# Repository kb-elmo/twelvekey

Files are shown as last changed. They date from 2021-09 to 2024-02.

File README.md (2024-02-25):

# Twelvekey

[][cc-by-nc-sa]<a href="https://ko-fi.com/kb_elmo">kofibadge</a>

### Simple 12-key mechanical macropad

front_view

---

[STEP files for the case](case/)

[KiCAD PCB files](pcb/)

[Gerbers for PCB production](pcb/fab/twelvekey.zip)

[JLCPCB BOM](pcb/fab/twelvekey_bom_jlc.csv)

[JLCPCB CPL](pcb/fab/twelvekey_cpl_jlc.csv)

[Vial-QMK firmware](firmware/vial-qmk)

---

back_view

---

This work is licensed under a
[Creative Commons Attribution-NonCommercial-ShareAlike 4.0 International License][cc-by-nc-sa].

[][cc-by-nc-sa]

[cc-by-nc-sa]: http://creativecommons.org/licenses/by-nc-sa/4.0/
[cc-by-nc-sa-image]: https://licensebuttons.net/l/by-nc-sa/4.0/88x31.png
[cc-by-nc-sa-shield]: https://img.shields.io/badge/License-CC%20BY--NC--SA%204.0-lightgrey.svg

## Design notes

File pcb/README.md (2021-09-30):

# Twelvekey PCB

### Features

- In-switch LEDs
- Powered by an Atmega328p
- Basic ESD and overvoltage protection
- Centered USB type-C port for a detachable cable
- Fully programmable using [QMK](https://qmk.fm) and [Vial](https://get.vial.today)

---

### Preview

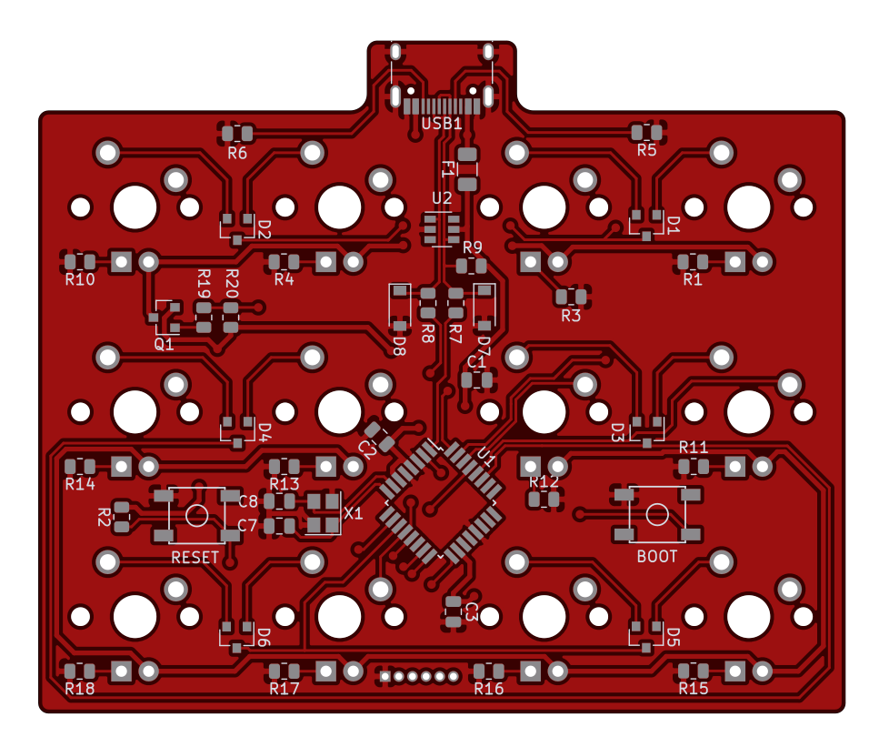
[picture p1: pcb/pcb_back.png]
pcb_back
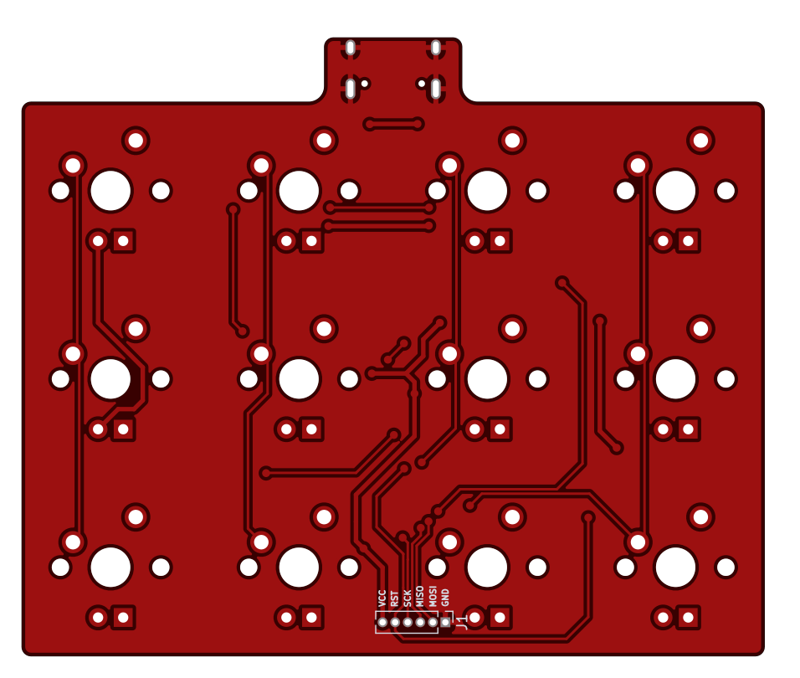
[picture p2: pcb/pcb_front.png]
pcb_front


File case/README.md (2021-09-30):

# Twelvekey case

### These files are meant for 3D printing only! 

They are not suitable for CNC machining and trying to use them for that will most likely result in failure of the parts.

The top piece should be printed upside down with supports for the integrated plate to get the best looking results.  
The bottom can be printed without any supports in it's natural orientation.

The bottom part is a simple friction fit into the top.  
Make sure that everything works and is installed properly on the PCB when putting the case together.  
Removing the bottom piece later is not really easy.

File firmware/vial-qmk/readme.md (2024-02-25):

# Twelvekey

twelvekey

Simple 12-key macropad

* Keyboard Maintainer: [kb-elmo](https://github.com/kb-elmo)
* Hardware Supported: Twelvekey PCB with backlight
* Hardware Availability: [Open source project](https://github.com/kb-elmo/twelvekey)

Make example for this keyboard (after setting up your build environment):

    make kb_elmo/twelvekey:default

Flashing example for this keyboard:

    make kb_elmo/twelvekey:default:flash

See the [build environment setup](https://docs.qmk.fm/#/getting_started_build_tools) and the [make instructions](https://docs.qmk.fm/#/getting_started_make_guide) for more information. Brand new to QMK? Start with our [Complete Newbs Guide](https://docs.qmk.fm/#/newbs).

## Bootloader

* **Bootmagic reset**: Hold down the top left key and plug in the keyboard
* **Physical reset button**: Hold down the button labeled "BOOT" and briefly press the button labeled "RESET" on the back of the PCB

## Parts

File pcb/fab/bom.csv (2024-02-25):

Designator | Footprint | Quantity | Value | LCSC Part #
BOOT, RESET | SKQG-1155865 | 2 | SW_Push | C2762971
C1 | 0805 | 1 | 10uF | C1713
C2, C3 | 0805 | 2 | 0.1uF | C38141
C7, C8 | 0805 | 2 | 22pF | C24658
D1, D2, D3, D4, D5, D6 | D_SOT-23_ANK | 6 | D_Small | C408391
D7, D8 | D_SOD-123 | 2 | D_Zener_Small | C173412
F1 | 1206 | 1 | Polyfuse_Small | C151133
J1 | PinHeader_1x06_P1.27mm_Vertical | 1 | Conn_01x06
MX1, MX10, MX11, MX12, MX2, MX3, MX4, MX5, MX6, MX7, MX8, MX9 | MXOnly-1U | 12 | MX-LED
Q1 | SOT-23 | 1 | AO3401A | C15127
R1, R10, R11, R12, R13, R14, R15, R16, R17, R18, R3, R4 | 0805 | 12 | 1k | C17513
R19 | 0805 | 1 | 100R | C17408
R2, R20 | 0805 | 2 | 10k | C17414
R5, R6 | 0805 | 2 | 5.1k | C27834
R7, R8 | 0805 | 2 | 68R | C17802
R9 | 0805 | 1 | 1.5K | C4310
U1 | TQFP-32_7x7mm_P0.8mm | 1 | ATmega328P-A | C14877
U2 | SOT-23-6 | 1 | SRV05-4 | C558418
USB1 | USB_C_Receptacle_HRO_TYPE-C-31-M-12 | 1 | USB_C_Receptacle_USB2.0 | C165948
X1 | Crystal_SMD_3225-4Pin_3.2x2.5mm | 1 | Crystal_GND24_Small | C13738

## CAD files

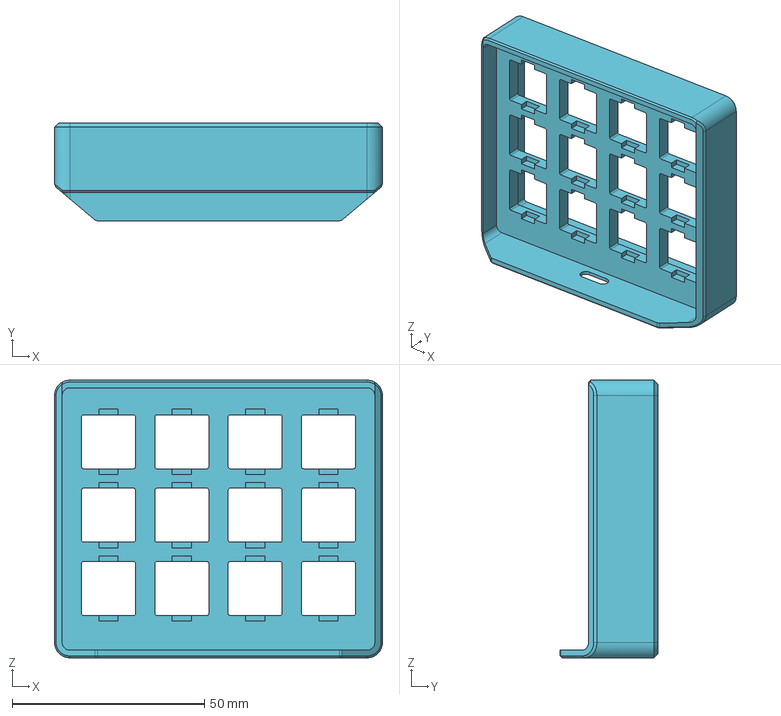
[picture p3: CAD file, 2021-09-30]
case/top.step
85.2 x 25.4 x 72.2 mm

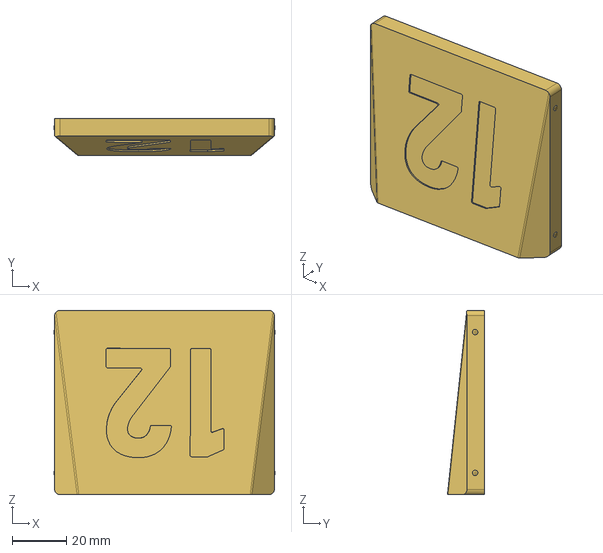
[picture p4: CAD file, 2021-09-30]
case/bottom.step
81.2 x 13.7 x 67.8 mm

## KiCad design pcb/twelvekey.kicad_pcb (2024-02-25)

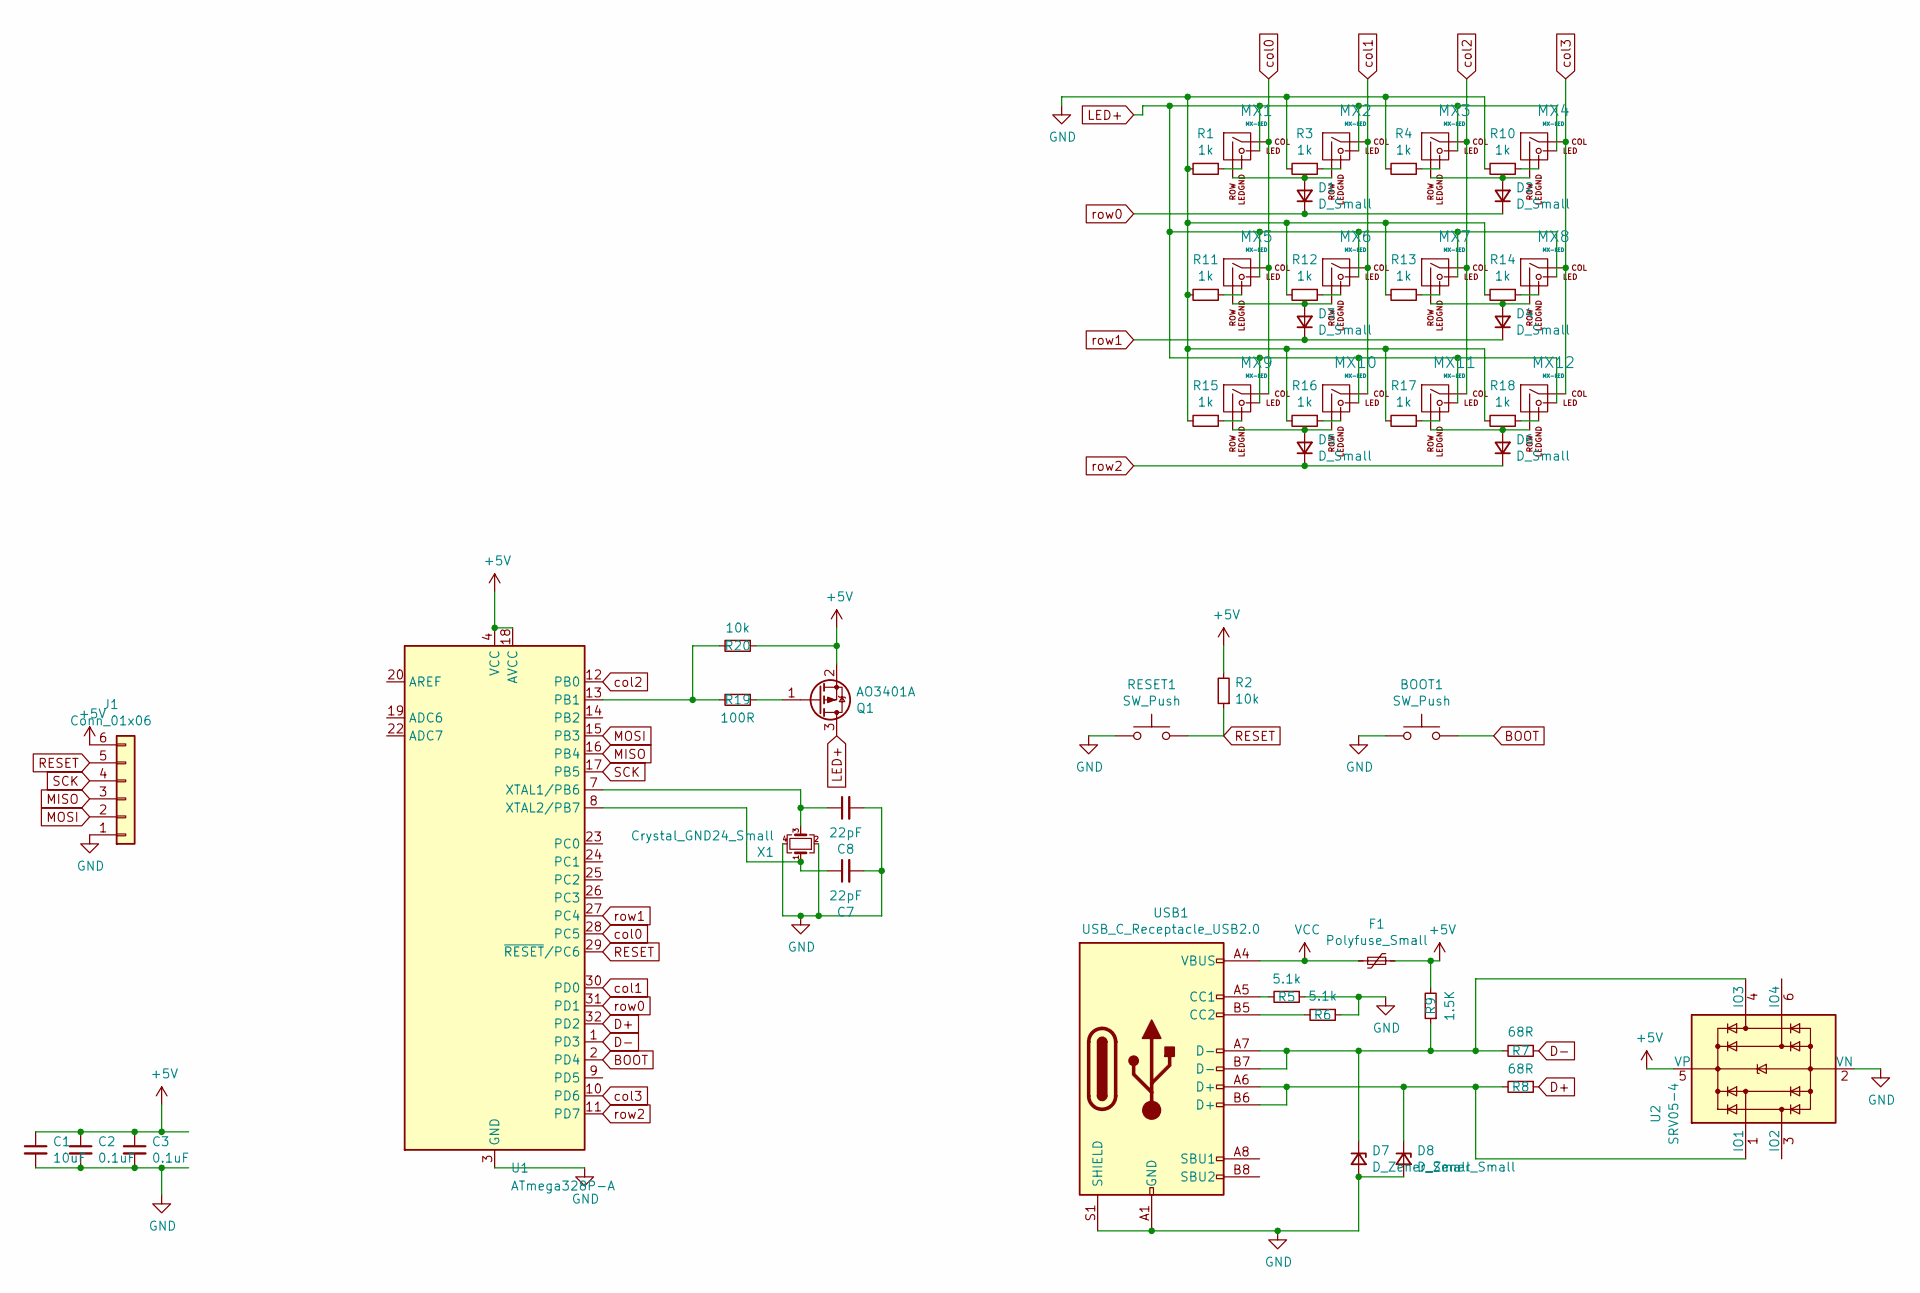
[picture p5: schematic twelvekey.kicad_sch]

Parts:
BOOT1: SW_Push; SKQG-1155865; LCSC C2762971
C1: 10uF; C_0805_2012Metric; LCSC C1713
C2, C3: 0.1uF; C_0805_2012Metric; LCSC C38141
C7, C8: 22pF; C_0805_2012Metric; LCSC C24658
D1, D2, D3, D4, D5, D6: D_Small; D_SOT-23_ANK; LCSC C408391
D7, D8: D_Zener_Small; D_SOD-123; LCSC C173412
F1: Polyfuse_Small; Fuse_1206_3216Metric; LCSC C151133
J1: Conn_01x06; PinHeader_1x06_P1.27mm_Vertical
MX1, MX2, MX3, MX4, MX5, MX6, MX7, MX8, MX9, MX10, MX11, MX12: MX-LED; MXOnly-1U
Q1: AO3401A; SOT-23; LCSC C15127
R1, R3, R4, R10, R11, R12, R13, R14, R15, R16, R17, R18: 1k; R_0805_2012Metric; LCSC C17513
R2, R20: 10k; R_0805_2012Metric; LCSC C17414
R5, R6: 5.1k; R_0805_2012Metric; LCSC C27834
R7, R8: 68R; R_0805_2012Metric; LCSC C17802
R9: 1.5K; R_0805_2012Metric; LCSC C4310
R19: 100R; R_0805_2012Metric; LCSC C17408
RESET1: SW_Push; SKQG-1155865; LCSC C2762971
U1: ATmega328P-A; TQFP-32_7x7mm_P0.8mm; LCSC C14877
U2: SRV05-4; SOT-23-6; LCSC C558418
USB1: USB_C_Receptacle_USB2.0; USB_C_Receptacle_HRO_TYPE-C-31-M-12; LCSC C165948
X1: Crystal_GND24_Small; Crystal_SMD_3225-4Pin_3.2x2.5mm; LCSC C13738

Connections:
+5V: C1.1, C2.1, C3.1, F1.1, J1.6, Q1.2 (S), R2.2, R9.2, R20.1, U1.4 (VCC), U1.6 (VCC), U1.18 (AVCC), U2.5 (VP)
BOOT: BOOT1.2, U1.2 (PD4); also elsewhere on the board
D+: R8.1, U1.32 (PD2)
D-: R7.1, U1.1 (PD3)
GND: BOOT1.1, C1.2, C2.2, C3.2, C7.2, C8.2, D7.2 (A), D8.2 (A), J1.1, R1.2, R3.2, R4.2, R5.1, R6.1, R10.2, R11.2, R12.2, R13.2, R14.2, R15.2, R16.2, R17.2, R18.2, RESET1.1, U1.3 (GND), U1.5 (GND), U1.21 (GND), U2.2 (VN), USB1.A1 (GND), USB1.A12 (GND), USB1.B1 (GND), USB1.B12 (GND), USB1.S1 (SHIELD), X1.2, X1.4; also elsewhere on the board
LED+: MX1.3 (LED), MX2.3 (LED), MX3.3 (LED), MX4.3 (LED), MX5.3 (LED), MX6.3 (LED), MX7.3 (LED), MX8.3 (LED), MX9.3 (LED), MX10.3 (LED), MX11.3 (LED), MX12.3 (LED), Q1.3 (D)
MISO: J1.3, U1.16 (PB4)
MOSI: J1.2, U1.15 (PB3)
unnamed: D1.2 (A), MX1.2 (ROW), MX2.2 (ROW)
unnamed: D2.2 (A), MX3.2 (ROW), MX4.2 (ROW)
unnamed: D3.2 (A), MX5.2 (ROW), MX6.2 (ROW)
unnamed: D4.2 (A), MX7.2 (ROW), MX8.2 (ROW)
unnamed: D5.2 (A), MX9.2 (ROW), MX10.2 (ROW)
unnamed: D6.2 (A), MX11.2 (ROW), MX12.2 (ROW)
unnamed: D7.1 (K), R7.2, R9.1, U2.4 (IO3), USB1.A7 (D-), USB1.B7 (D-)
unnamed: D8.1 (K), R8.2, U2.1 (IO1), USB1.A6 (D+), USB1.B6 (D+)
unnamed: MX1.4 (LEDGND), R1.1
unnamed: MX2.4 (LEDGND), R3.1
unnamed: MX3.4 (LEDGND), R4.1
unnamed: MX4.4 (LEDGND), R10.1
unnamed: MX5.4 (LEDGND), R11.1
unnamed: MX6.4 (LEDGND), R12.1
unnamed: MX7.4 (LEDGND), R13.1
unnamed: MX8.4 (LEDGND), R14.1
unnamed: MX9.4 (LEDGND), R15.1
unnamed: MX10.4 (LEDGND), R16.1
unnamed: MX11.4 (LEDGND), R17.1
unnamed: MX12.4 (LEDGND), R18.1
unnamed: Q1.1 (G), R19.1
unnamed: R19.2, R20.2, U1.13 (PB1)
unnamed: C8.1, U1.7 (XTAL1/PB6), X1.3
unnamed: C7.1, U1.8 (XTAL2/PB7), X1.1
unnamed: R5.2, USB1.A5 (CC1)
unnamed: R6.2, USB1.B5 (CC2)
RESET: J1.5, R2.1, RESET1.2, U1.29 (~RESET/PC6); also elsewhere on the board
SCK: J1.4, U1.17 (PB5)
VCC: F1.2, USB1.A4 (VBUS), USB1.A9 (VBUS), USB1.B4 (VBUS), USB1.B9 (VBUS)
col0: MX1.1 (COL), MX5.1 (COL), MX9.1 (COL), U1.28 (PC5)
col1: MX2.1 (COL), MX6.1 (COL), MX10.1 (COL), U1.30 (PD0)
col2: MX3.1 (COL), MX7.1 (COL), MX11.1 (COL), U1.12 (PB0)
col3: MX4.1 (COL), MX8.1 (COL), MX12.1 (COL), U1.10 (PD6)
row0: D1.1 (K), D2.1 (K), U1.31 (PD1)
row1: D3.1 (K), D4.1 (K), U1.27 (PC4)
row2: D5.1 (K), D6.1 (K), U1.11 (PD7)

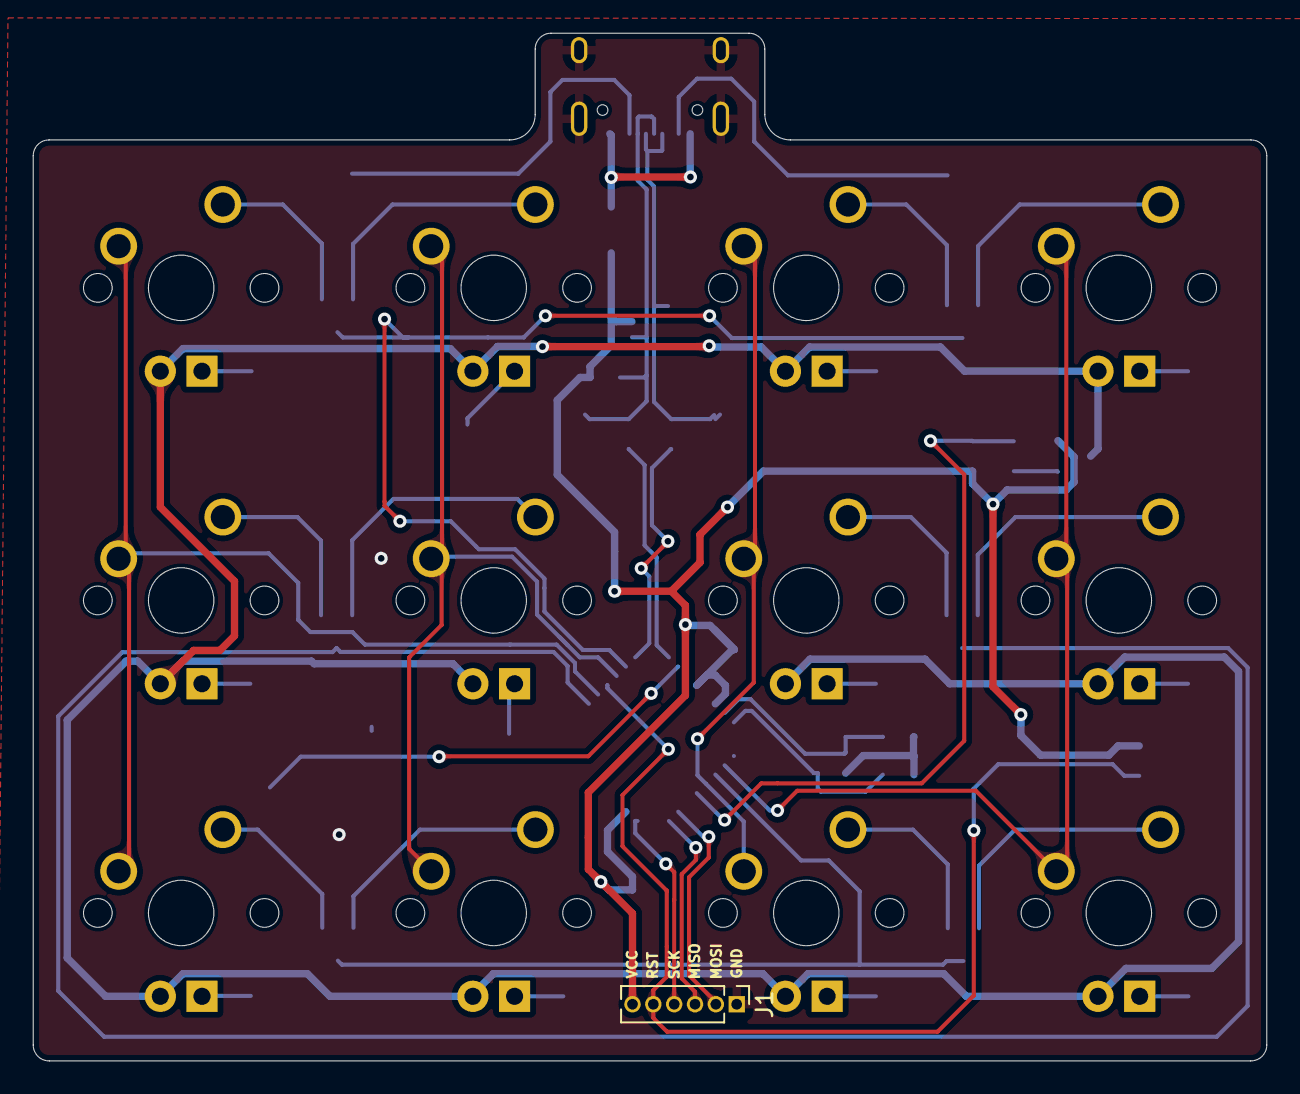
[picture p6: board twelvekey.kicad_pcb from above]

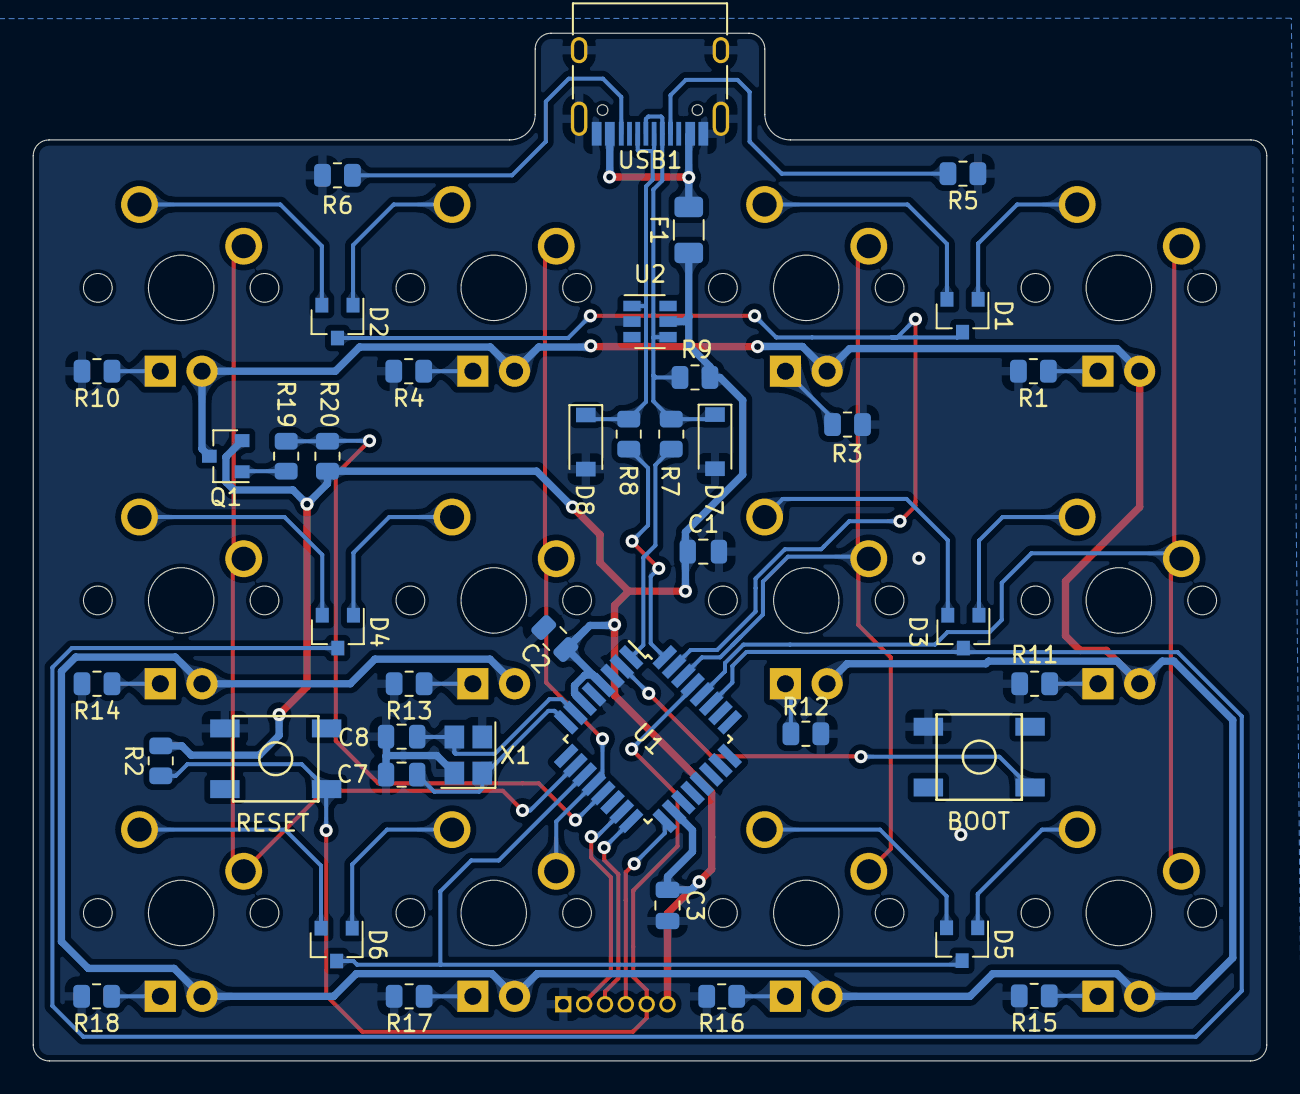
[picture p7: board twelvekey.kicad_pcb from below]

Board: 2 copper layers, 75.2 x 62.6 mm, 54 parts (41 on the bottom side), 44 nets.

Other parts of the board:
BOOT: SW_Push; SKQG-1155865
RESET: SW_Push; SKQG-1155865

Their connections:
BOOT: BOOT.2; also elsewhere on the board
GND: BOOT.1, RESET.1; also elsewhere on the board
RESET: RESET.2; also elsewhere on the board

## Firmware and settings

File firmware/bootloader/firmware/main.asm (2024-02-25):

main.elf:     file format elf32-avr

SYMBOL TABLE:
00800100 l    d  .data	00000000 .data
00007000 l    d  .text	00000000 .text
00800106 l    d  .bss	00000000 .bss
0080013b l    d  .noinit	00000000 .noinit
00000000 l    d  .stab	00000000 .stab
00000000 l    d  .stabstr	00000000 .stabstr
00000000 l    d  .comment	00000000 .comment
00000000 l    d  .note.gnu.avr.deviceinfo	00000000 .note.gnu.avr.deviceinfo
00000000 l    d  .debug_info	00000000 .debug_info
00000000 l    d  .debug_abbrev	00000000 .debug_abbrev
00000000 l    d  .debug_line	00000000 .debug_line
00000000 l    d  .debug_str	00000000 .debug_str
00000000 l    df *ABS*	00000000 main.c
0000003e l       *ABS*	00000000 __SP_H__
0000003d l       *ABS*	00000000 __SP_L__
0000003f l       *ABS*	00000000 __SREG__
00000000 l       *ABS*	00000000 __tmp_reg__
00000001 l       *ABS*	00000000 __zero_reg__
000070f4 l       .text	00000000 __BOOTLOADERENTRY_FROMSOFTWARE__bootup_investigate_RAMEND_done5
000070f2 l       .text	00000000 __BOOTLOADERENTRY_FROMSOFTWARE__bootup_investigate_RAMEND_mismatch5
0080013c l     O .noinit	00000001 __BOOTLOADERENTRY_FROMSOFTWARE__bootup_RAMEND_doesmatch
0080013b l     O .noinit	00000001 __BOOTLOADERENTRY_FROMSOFTWARE__bootup_MCUCSR
00800102 l     O .data	00000004 signatureBytes
0080010f l     O .bss	00000001 stayinloader
00007430 l       .text	00000000 _mywait_sleeploop156
00007496 l       .text	00000000 _mywait_sleeploop231
00800110 l     O .bss	00000001 usbMsgFlags
00800106 l     O .bss	00000004 replyBuffer.2269
0080010d l     O .bss	00000002 currentAddress
0080010c l     O .bss	00000001 bytesRemaining
0080010b l     O .bss	00000001 isLastPage
0080010a l     O .bss	00000001 currentRequest
00800100 l     O .data	00000001 usbMsgLen
00000000 l    df *ABS*	00000000 _clear_bss.o
0000711c l       .text	00000000 .do_clear_bss_start
0000711a l       .text	00000000 .do_clear_bss_loop
00000000 l    df *ABS*	00000000 usbdrv/usbdrvasm.o
0000714c l       .text	00000000 usbCrcLoopEntry
0000713a l       .text	00000000 usbCrcByteLoop
0000713e l       .text	00000000 usbCrcBitLoop
00007148 l       .text	00000000 usbCrcNoXor
00007150 l       .text	00000000 usbCrcReady
00007162 l       .text	00000000 waitForJ
00007168 l       .text	00000000 waitForK
00007182 l       .text	00000000 foundK
00007294 l       .text	00000000 sofError
0000719c l       .text	00000000 haveTwoBitsK
0000722a l       .text	00000000 rxbit1
000071b8 l       .text	00000000 unstuff6
00007200 l       .text	00000000 didUnstuff6
000071c4 l       .text	00000000 unstuff7
0000720e l       .text	00000000 didUnstuff7
000071d0 l       .text	00000000 unstuffEven
0000724e l       .text	00000000 se0
00007226 l       .text	00000000 didUnstuffE
000071e0 l       .text	00000000 unstuffOdd
0000723a l       .text	00000000 didUnstuffO
000071f0 l       .text	00000000 rxByteLoop
000071fc l       .text	00000000 skipLeap
00007216 l       .text	00000000 rxBitLoop
00007246 l       .text	00000000 overflow
0000724a l       .text	00000000 ignorePacket
0000727c l       .text	00000000 storeTokenAndReturn
0000729e l       .text	00000000 handleData
000072c8 l       .text	00000000 handleIn
0000727c l       .text	00000000 handleSetupOrOut
00007280 l       .text	00000000 doReturn
000072fc l       .text	00000000 sendNakAndReti
00007300 l       .text	00000000 sendAckAndReti
00007302 l       .text	00000000 sendCntAndReti
0000730a l       .text	00000000 usbSendAndReti
000072e4 l       .text	00000000 bitstuffN
00007324 l       .text	00000000 didStuffN
000072f0 l       .text	00000000 bitstuff6
00007332 l       .text	00000000 didStuff6
000072f8 l       .text	00000000 bitstuff7
0000733e l       .text	00000000 didStuff7
00007304 l       .text	00000000 sendX3AndReti
00007318 l       .text	00000000 txByteLoop
0000731a l       .text	00000000 txBitLoop
00007366 l       .text	00000000 skipAddrAssign
00007376 l       .text	00000000 se0Delay
00000000 l    df *ABS*	00000000 _exit.o
0000788a l       .text	00000000 __stop_program
00007098 g     O .text	00000012 usbDescriptorDevice
00007126  w      .text	00000000 __vector_22
0000786e g       .text	00000000 eeprom_write_r18
0000715a g     F .text	00000000 __vector_1
00800111 g     O .bss	0000000b usbTxBuf
00000000 g       *ABS*	00000000 nullVector
00000800 g       *ABS*	00000000 __DATA_REGION_LENGTH__
00000000 g       *ABS*	00000000 __TEXT_REGION_ORIGIN__
00007086 g       .text	00000000 __trampolines_start
0000788c g       .text	00000000 _etext
000070d4 g     O .text	00000004 usbDescriptorString0
00007126  w      .text	00000000 __vector_24
00007126  w      .text	00000000 __vector_12
00007126 g       .text	00000000 __bad_interrupt
00007892 g       *ABS*	00000000 __data_load_end
00007126  w      .text	00000000 __vector_6
00007128 g       .text	00000000 usbCrc16
00007086 g       .text	00000000 __trampolines_end
00007126  w      .text	00000000 __vector_3
000070e4 g     F .text	00000018 __BOOTLOADERENTRY_FROMSOFTWARE__bootup_investigate_RAMEND
00007126  w      .text	00000000 __vector_23
0000788c g       *ABS*	00000000 __data_load_start
000070d8 g       .text	00000000 __dtors_end
0080013b g       .bss	00000000 __bss_end
00000400 g       *ABS*	00000000 __LOCK_REGION_LENGTH__
00007126  w      .text	00000000 __vector_25
00007068 g     O .text	0000001e bootloader__do_spm
0000786c g     F .text	0000001c eeprom_write_byte
00007126  w      .text	00000000 __vector_11
000070d8  w      .text	00000000 __init
00007126  w      .text	00000000 __vector_13
00007152 g       .text	00000000 usbCrc16Append
00007126  w      .text	00000000 __vector_17
00007126  w      .text	00000000 __vector_19
00007126  w      .text	00000000 __vector_7
00007086 g     O .text	00000012 usbDescriptorConfiguration
00007112 g       .text	00000010 .hidden __do_clear_bss
0080011c g     O .bss	00000001 usbDeviceAddr
00810000 g       .stab	00000000 __eeprom_end
0080011d g     O .bss	00000001 usbRxToken
00007000 g       .text	00000000 __vectors
0000785c g     F .text	00000010 eeprom_read_byte
00800106 g       .data	00000000 __data_end
000070b8 g     O .text	0000001c usbDescriptorStringVendor
0080011e g     O .bss	00000001 usbInputBufOffset
00007000  w      .text	00000000 __vector_default
00007126  w      .text	00000000 __vector_5
00000400 g       *ABS*	00000000 __SIGNATURE_REGION_LENGTH__
000070d8 g       .text	00000000 __ctors_start
000070fc g       .text	00000016 .hidden __do_copy_data
00007382 g     F .text	0000009c usbFunctionSetup_USBASP_FUNC_TRANSMIT
00800106 g       .bss	00000000 __bss_start
0000741e g     F .text	0000043e main
00007126  w      .text	00000000 __vector_4
00800100 g       *ABS*	00000000 __DATA_REGION_ORIGIN__
00800101 g     O .data	00000001 usbTxLen
00000000  w      *ABS*	00000000 __heap_end
00007126  w      .text	00000000 __vector_9
00007126  w      .text	00000000 __vector_2
00000400 g       *ABS*	00000000 __USER_SIGNATURE_REGION_LENGTH__
0080011f g     O .bss	00000002 usbMsgPtr
00007126  w      .text	00000000 __vector_21
00007126  w      .text	00000000 __vector_15
00800121 g     O .bss	00000001 usbRxLen
000070d8 g       .text	00000000 __dtors_start
000070d8 g       .text	00000000 __ctors_end
000008ff  w      *ABS*	00000000 __stack
00800122 g     O .bss	00000001 usbNewDeviceAddr
00800106 g       .data	00000000 _edata
0080013d g       .noinit	00000000 _end
00007126  w      .text	00000000 __vector_8
00007888  w      .text	00000000 .hidden exit
00800123 g     O .bss	00000001 usbCurrentTok
000070aa g     O .text	0000000e usbDescriptorStringDevice
00000400 g       *ABS*	00000000 __EEPROM_REGION_LENGTH__
00007888 g       .text	00000000 .hidden _exit
00800124 g     O .bss	00000001 usbConfiguration
00007126  w      .text	00000000 __vector_14
00007126  w      .text	00000000 __vector_10
00800125 g     O .bss	00000016 usbRxBuf
00007126  w      .text	00000000 __vector_16
00800100 g       .data	00000000 __data_start
00007126  w      .text	00000000 __vector_18
00000003 g       *ABS*	00000000 __FUSE_REGION_LENGTH__
00008000 g       *ABS*	00000000 __TEXT_REGION_LENGTH__
00007126  w      .text	00000000 __vector_20



Disassembly of section .text:

00007000 <__vectors>:
    7000:	6b c0       	rjmp	.+214    	; 0x70d8 <__ctors_end>
    7002:	00 00       	nop
    7004:	aa c0       	rjmp	.+340    	; 0x715a <__vector_1>
    7006:	00 00       	nop
    7008:	8e c0       	rjmp	.+284    	; 0x7126 <__bad_interrupt>
    700a:	00 00       	nop
    700c:	8c c0       	rjmp	.+280    	; 0x7126 <__bad_interrupt>
    700e:	00 00       	nop
    7010:	8a c0       	rjmp	.+276    	; 0x7126 <__bad_interrupt>
    7012:	00 00       	nop
    7014:	88 c0       	rjmp	.+272    	; 0x7126 <__bad_interrupt>
    7016:	00 00       	nop
    7018:	86 c0       	rjmp	.+268    	; 0x7126 <__bad_interrupt>
    701a:	00 00       	nop
    701c:	84 c0       	rjmp	.+264    	; 0x7126 <__bad_interrupt>
    701e:	00 00       	nop
    7020:	82 c0       	rjmp	.+260    	; 0x7126 <__bad_interrupt>
    7022:	00 00       	nop
    7024:	80 c0       	rjmp	.+256    	; 0x7126 <__bad_interrupt>
    7026:	00 00       	nop
    7028:	7e c0       	rjmp	.+252    	; 0x7126 <__bad_interrupt>
    702a:	00 00       	nop
    702c:	7c c0       	rjmp	.+248    	; 0x7126 <__bad_interrupt>
    702e:	00 00       	nop
    7030:	7a c0       	rjmp	.+244    	; 0x7126 <__bad_interrupt>
    7032:	00 00       	nop
    7034:	78 c0       	rjmp	.+240    	; 0x7126 <__bad_interrupt>
    7036:	00 00       	nop
    7038:	76 c0       	rjmp	.+236    	; 0x7126 <__bad_interrupt>
    703a:	00 00       	nop
    703c:	74 c0       	rjmp	.+232    	; 0x7126 <__bad_interrupt>
    703e:	00 00       	nop
    7040:	72 c0       	rjmp	.+228    	; 0x7126 <__bad_interrupt>
    7042:	00 00       	nop
    7044:	70 c0       	rjmp	.+224    	; 0x7126 <__bad_interrupt>
    7046:	00 00       	nop
    7048:	6e c0       	rjmp	.+220    	; 0x7126 <__bad_interrupt>
    704a:	00 00       	nop
    704c:	6c c0       	rjmp	.+216    	; 0x7126 <__bad_interrupt>
    704e:	00 00       	nop
    7050:	6a c0       	rjmp	.+212    	; 0x7126 <__bad_interrupt>
    7052:	00 00       	nop
    7054:	68 c0       	rjmp	.+208    	; 0x7126 <__bad_interrupt>
    7056:	00 00       	nop
    7058:	66 c0       	rjmp	.+204    	; 0x7126 <__bad_interrupt>
    705a:	00 00       	nop
    705c:	64 c0       	rjmp	.+200    	; 0x7126 <__bad_interrupt>
    705e:	00 00       	nop
    7060:	62 c0       	rjmp	.+196    	; 0x7126 <__bad_interrupt>
    7062:	00 00       	nop
    7064:	60 c0       	rjmp	.+192    	; 0x7126 <__bad_interrupt>
	...

00007068 <bootloader__do_spm>:
    7068:	ec 2d fd 2d b7 b6 b0 fc fd cf 27 bf e8 95 b7 b6     .-.-......'.....
    7078:	b0 fc fd cf 21 e1 b7 b6 b6 fc f4 cf 08 95           ....!.........

00007086 <__trampolines_end>:
    7086:	09 02       	muls	r16, r25
    7088:	12 00       	.word	0x0012	; ????
    708a:	01 01       	movw	r0, r2
    708c:	00 80       	ld	r0, Z
    708e:	32 09       	sbc	r19, r2
    7090:	04 00       	.word	0x0004	; ????
    7092:	00 00       	nop
    7094:	00 00       	nop
	...

00007098 <usbDescriptorDevice>:
    7098:	12 01 10 01 ff 00 00 08 c0 16 dc 05 02 01 01 02     ................
    70a8:	00 01                                               ..

000070aa <usbDescriptorStringDevice>:
    70aa:	0e 03 55 00 53 00 42 00 61 00 73 00 70 00           ..U.S.B.a.s.p.

000070b8 <usbDescriptorStringVendor>:
    70b8:	1c 03 77 00 77 00 77 00 2e 00 66 00 69 00 73 00     ..w.w.w...f.i.s.
    70c8:	63 00 68 00 6c 00 2e 00 64 00 65 00                 c.h.l...d.e.

000070d4 <usbDescriptorString0>:
    70d4:	04 03 09 04                                         ....

000070d8 <__ctors_end>:
    70d8:	11 24       	eor	r1, r1
    70da:	1f be       	out	0x3f, r1	; 63
    70dc:	cf ef       	ldi	r28, 0xFF	; 255
    70de:	d8 e0       	ldi	r29, 0x08	; 8
    70e0:	de bf       	out	0x3e, r29	; 62
    70e2:	cd bf       	out	0x3d, r28	; 61

000070e4 <__BOOTLOADERENTRY_FROMSOFTWARE__bootup_investigate_RAMEND>:
    70e4:	24 b7       	in	r18, 0x34	; 52
    70e6:	d8 e0       	ldi	r29, 0x08	; 8
    70e8:	ce ef       	ldi	r28, 0xFE	; 254
    70ea:	39 91       	ld	r19, Y+
    70ec:	38 33       	cpi	r19, 0x38	; 56
    70ee:	39 91       	ld	r19, Y+
    70f0:	09 f0       	breq	.+2      	; 0x70f4 <__BOOTLOADERENTRY_FROMSOFTWARE__bootup_investigate_RAMEND_done5>

000070f2 <__BOOTLOADERENTRY_FROMSOFTWARE__bootup_investigate_RAMEND_mismatch5>:
    70f2:	3f ef       	ldi	r19, 0xFF	; 255

000070f4 <__BOOTLOADERENTRY_FROMSOFTWARE__bootup_investigate_RAMEND_done5>:
    70f4:	30 93 3c 01 	sts	0x013C, r19	; 0x80013c <__BOOTLOADERENTRY_FROMSOFTWARE__bootup_RAMEND_doesmatch>
    70f8:	20 93 3b 01 	sts	0x013B, r18	; 0x80013b <__bss_end>

000070fc <__do_copy_data>:
    70fc:	11 e0       	ldi	r17, 0x01	; 1
    70fe:	a0 e0       	ldi	r26, 0x00	; 0
    7100:	b1 e0       	ldi	r27, 0x01	; 1
    7102:	ec e8       	ldi	r30, 0x8C	; 140
    7104:	f8 e7       	ldi	r31, 0x78	; 120
    7106:	02 c0       	rjmp	.+4      	; 0x710c <__do_copy_data+0x10>
    7108:	05 90       	lpm	r0, Z+
    710a:	0d 92       	st	X+, r0
    710c:	a6 30       	cpi	r26, 0x06	; 6
    710e:	b1 07       	cpc	r27, r17
    7110:	d9 f7       	brne	.-10     	; 0x7108 <__do_copy_data+0xc>

00007112 <__do_clear_bss>:
    7112:	21 e0       	ldi	r18, 0x01	; 1
    7114:	a6 e0       	ldi	r26, 0x06	; 6
    7116:	b1 e0       	ldi	r27, 0x01	; 1
    7118:	01 c0       	rjmp	.+2      	; 0x711c <.do_clear_bss_start>

0000711a <.do_clear_bss_loop>:
    711a:	1d 92       	st	X+, r1

0000711c <.do_clear_bss_start>:
    711c:	ab 33       	cpi	r26, 0x3B	; 59
    711e:	b2 07       	cpc	r27, r18
    7120:	e1 f7       	brne	.-8      	; 0x711a <.do_clear_bss_loop>
    7122:	7d d1       	rcall	.+762    	; 0x741e <main>
    7124:	b1 c3       	rjmp	.+1890   	; 0x7888 <_exit>

00007126 <__bad_interrupt>:
    7126:	6c cf       	rjmp	.-296    	; 0x7000 <__vectors>

00007128 <usbCrc16>:
;   poly    r20+r21
;   scratch r23
;   resCrc  r24+r25 / r16+r17
;   ptr     X / Z
usbCrc16:
    mov     ptrL, argPtrL
    7128:	a8 2f       	mov	r26, r24
    mov     ptrH, argPtrH
    712a:	b9 2f       	mov	r27, r25
    ldi     resCrcL, 0
    712c:	80 e0       	ldi	r24, 0x00	; 0
    ldi     resCrcH, 0
    712e:	90 e0       	ldi	r25, 0x00	; 0
    ldi     polyL, lo8(0xa001)
    7130:	41 e0       	ldi	r20, 0x01	; 1
    ldi     polyH, hi8(0xa001)
    7132:	50 ea       	ldi	r21, 0xA0	; 160
    com     argLen      ; argLen = -argLen - 1: modified loop to ensure that carry is set
    7134:	60 95       	com	r22
    ldi     bitCnt, 0   ; loop counter with starnd condition = end condition
    7136:	30 e0       	ldi	r19, 0x00	; 0
    rjmp    usbCrcLoopEntry
    7138:	09 c0       	rjmp	.+18     	; 0x714c <usbCrcLoopEntry>

0000713a <usbCrcByteLoop>:
usbCrcByteLoop:
    ld      byte, ptr+
    713a:	2d 91       	ld	r18, X+
    eor     resCrcL, byte
    713c:	82 27       	eor	r24, r18

0000713e <usbCrcBitLoop>:
usbCrcBitLoop:
    ror     resCrcH     ; carry is always set here (see brcs jumps to here)
    713e:	97 95       	ror	r25
    ror     resCrcL
    7140:	87 95       	ror	r24
    brcs    usbCrcNoXor
    7142:	10 f0       	brcs	.+4      	; 0x7148 <usbCrcNoXor>
    eor     resCrcL, polyL
    7144:	84 27       	eor	r24, r20
    eor     resCrcH, polyH
    7146:	95 27       	eor	r25, r21

00007148 <usbCrcNoXor>:
usbCrcNoXor:
    subi    bitCnt, 224 ; (8 * 224) % 256 = 0; this loop iterates 8 times
    7148:	30 5e       	subi	r19, 0xE0	; 224
    brcs    usbCrcBitLoop
    714a:	c8 f3       	brcs	.-14     	; 0x713e <usbCrcBitLoop>

0000714c <usbCrcLoopEntry>:
usbCrcLoopEntry:
    subi    argLen, -1
    714c:	6f 5f       	subi	r22, 0xFF	; 255
    brcs    usbCrcByteLoop
    714e:	a8 f3       	brcs	.-22     	; 0x713a <usbCrcByteLoop>

00007150 <usbCrcReady>:
usbCrcReady:
    ret
    7150:	08 95       	ret

00007152 <usbCrc16Append>:

#endif /* USB_USE_FAST_CRC */

; extern unsigned usbCrc16Append(unsigned char *data, unsigned char len);
usbCrc16Append:
    rcall   usbCrc16
    7152:	ea df       	rcall	.-44     	; 0x7128 <usbCrc16>
    st      ptr+, resCrcL
    7154:	8d 93       	st	X+, r24
    st      ptr+, resCrcH
    7156:	9d 93       	st	X+, r25
    ret
    7158:	08 95       	ret

0000715a <__vector_1>:
; Numbers in brackets are clocks counted from center of last sync bit
; when instruction starts

USB_INTR_VECTOR:
;order of registers pushed: YL, SREG YH, [sofError], bitcnt, shift, x1, x2, x3, x4, cnt
    push    YL                  ;[-25] push only what is necessary to sync with edge ASAP
    715a:	cf 93       	push	r28
    in      YL, SREG            ;[-23]
    715c:	cf b7       	in	r28, 0x3f	; 63
    push    YL                  ;[-22]
    715e:	cf 93       	push	r28
    push    YH                  ;[-20]
    7160:	df 93       	push	r29

00007162 <waitForJ>:
;sync up with J to K edge during sync pattern -- use fastest possible loops
;The first part waits at most 1 bit long since we must be in sync pattern.
;YL is guarenteed to be < 0x80 because I flag is clear. When we jump to
;waitForJ, ensure that this prerequisite is met.
waitForJ:
    inc     YL
    7162:	c3 95       	inc	r28
    sbis    USBIN, USBMINUS
    7164:	4b 9b       	sbis	0x09, 3	; 9
    brne    waitForJ        ; just make sure we have ANY timeout
    7166:	e9 f7       	brne	.-6      	; 0x7162 <waitForJ>

00007168 <waitForK>:
waitForK:
;The following code results in a sampling window of < 1/4 bit which meets the spec.
    sbis    USBIN, USBMINUS     ;[-15]
    7168:	4b 9b       	sbis	0x09, 3	; 9
    rjmp    foundK              ;[-14]
    716a:	0b c0       	rjmp	.+22     	; 0x7182 <foundK>
    sbis    USBIN, USBMINUS
    716c:	4b 9b       	sbis	0x09, 3	; 9
    rjmp    foundK
    716e:	09 c0       	rjmp	.+18     	; 0x7182 <foundK>
    sbis    USBIN, USBMINUS
    7170:	4b 9b       	sbis	0x09, 3	; 9
    rjmp    foundK
    7172:	07 c0       	rjmp	.+14     	; 0x7182 <foundK>
    sbis    USBIN, USBMINUS
    7174:	4b 9b       	sbis	0x09, 3	; 9
    rjmp    foundK
    7176:	05 c0       	rjmp	.+10     	; 0x7182 <foundK>
    sbis    USBIN, USBMINUS
    7178:	4b 9b       	sbis	0x09, 3	; 9
    rjmp    foundK
    717a:	03 c0       	rjmp	.+6      	; 0x7182 <foundK>
    sbis    USBIN, USBMINUS
    717c:	4b 9b       	sbis	0x09, 3	; 9
    rjmp    foundK
    717e:	01 c0       	rjmp	.+2      	; 0x7182 <foundK>
    sts     usbSofCount, YL
#endif  /* USB_COUNT_SOF */
#ifdef USB_SOF_HOOK
    USB_SOF_HOOK
#endif
    rjmp    sofError
    7180:	89 c0       	rjmp	.+274    	; 0x7294 <sofError>

00007182 <foundK>:
foundK:                         ;[-12]
;{3, 5} after falling D- edge, average delay: 4 cycles [we want 5 for center sampling]
;we have 1 bit time for setup purposes, then sample again. Numbers in brackets
;are cycles from center of first sync (double K) bit after the instruction
    push    bitcnt              ;[-12]
    7182:	6f 93       	push	r22
;   [---]                       ;[-11]
    lds     YL, usbInputBufOffset;[-10]
    7184:	c0 91 1e 01 	lds	r28, 0x011E	; 0x80011e <usbInputBufOffset>
;   [---]                       ;[-9]
    clr     YH                  ;[-8]
    7188:	dd 27       	eor	r29, r29
    subi    YL, lo8(-(usbRxBuf));[-7] [rx loop init]
    718a:	cb 5d       	subi	r28, 0xDB	; 219
    sbci    YH, hi8(-(usbRxBuf));[-6] [rx loop init]
    718c:	de 4f       	sbci	r29, 0xFE	; 254
    push    shift               ;[-5]
    718e:	2f 93       	push	r18
;   [---]                       ;[-4]
    ldi     bitcnt, 0x55        ;[-3] [rx loop init]
    7190:	65 e5       	ldi	r22, 0x55	; 85
    sbis    USBIN, USBMINUS     ;[-2] we want two bits K (sample 2 cycles too early)
    7192:	4b 9b       	sbis	0x09, 3	; 9
    rjmp    haveTwoBitsK        ;[-1]
    7194:	03 c0       	rjmp	.+6      	; 0x719c <haveTwoBitsK>
    pop     shift               ;[0] undo the push from before
    7196:	2f 91       	pop	r18
    pop     bitcnt              ;[2] undo the push from before
    7198:	6f 91       	pop	r22
    rjmp    waitForK            ;[4] this was not the end of sync, retry
    719a:	e6 cf       	rjmp	.-52     	; 0x7168 <waitForK>

0000719c <haveTwoBitsK>:

;----------------------------------------------------------------------------
; push more registers and initialize values while we sample the first bits:
;----------------------------------------------------------------------------
haveTwoBitsK:
    push    x1              ;[1]
    719c:	0f 93       	push	r16
    push    x2              ;[3]
    719e:	1f 93       	push	r17
    push    x3              ;[5]
    71a0:	4f 93       	push	r20
    ldi     shift, 0        ;[7]
    71a2:	20 e0       	ldi	r18, 0x00	; 0
    ldi     x3, 1<<4        ;[8] [rx loop init] first sample is inverse bit, compensate that
    71a4:	40 e1       	ldi	r20, 0x10	; 16
    push    x4              ;[9] == leap
    71a6:	5f 93       	push	r21

    in      x1, USBIN       ;[11] <-- sample bit 0
    71a8:	09 b1       	in	r16, 0x09	; 9
    andi    x1, USBMASK     ;[12]
    71aa:	0c 70       	andi	r16, 0x0C	; 12
    bst     x1, USBMINUS    ;[13]
    71ac:	03 fb       	bst	r16, 3
    bld     shift, 7        ;[14]
    71ae:	27 f9       	bld	r18, 7
    push    cnt             ;[15]
    71b0:	3f 93       	push	r19
    ldi     leap, 0         ;[17] [rx loop init]
    71b2:	50 e0       	ldi	r21, 0x00	; 0
    ldi     cnt, USB_BUFSIZE;[18] [rx loop init]
    71b4:	3b e0       	ldi	r19, 0x0B	; 11
    rjmp    rxbit1          ;[19] arrives at [21]
    71b6:	39 c0       	rjmp	.+114    	; 0x722a <rxbit1>

000071b8 <unstuff6>:

; duration of unstuffing code should be 10.66666667 cycles. We adjust "leap"
; accordingly to approximate this value in the long run.
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

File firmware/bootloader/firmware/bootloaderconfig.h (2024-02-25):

/* Name: bootloaderconfig.h
 * Project: USBaspLoader
 * Author: Christian Starkjohann
 * Author: Stephan Baerwolf
 * Creation Date: 2007-12-08
 * Modification Date: 2013-03-31
 * Tabsize: 4
 * Copyright: (c) 2007 by OBJECTIVE DEVELOPMENT Software GmbH
 * License: GNU GPL v2 (see License.txt)
 */

#ifndef __bootloaderconfig_h_included__
#define __bootloaderconfig_h_included__
#include "../misc/iofixes.h"

/*
General Description:
This file (together with some settings in Makefile) configures the boot loader
according to the hardware.

This file contains (besides the hardware configuration normally found in
usbconfig.h) two functions or macros: bootLoaderInit() and
bootLoaderCondition(). Whether you implement them as macros or as static
inline functions is up to you, decide based on code size and convenience.

bootLoaderInit() is called as one of the first actions after reset. It should
be a minimum initialization of the hardware so that the boot loader condition
can be read. This will usually consist of activating a pull-up resistor for an
external jumper which selects boot loader mode.

bootLoaderCondition() is called immediately after initialization and in each
main loop iteration. If it returns TRUE, the boot loader will be active. If it
returns FALSE, the boot loader jumps to address 0 (the loaded application)
immediately.

For compatibility with Thomas Fischl's avrusbboot, we also support the macro
names BOOTLOADER_INIT and BOOTLOADER_CONDITION for this functionality. If
these macros are defined, the boot loader usees them.
*/

/* ---------------------------- Macro Magic ---------------------------- */
#define		PIN_CONCAT(a,b)			a ## b
#define		PIN_CONCAT3(a,b,c)		a ## b ## c

#define		PIN_PORT(a)			PIN_CONCAT(PORT, a)
#define		PIN_PIN(a)			PIN_CONCAT(PIN, a)
#define		PIN_DDR(a)			PIN_CONCAT(DDR, a)

#define		PIN(a, b)			PIN_CONCAT3(P, a, b)

/* ---------------------------- Hardware Config ---------------------------- */

#ifndef USB_CFG_IOPORTNAME
  #define USB_CFG_IOPORTNAME      D
#endif
/* This is the port where the USB bus is connected. When you configure it to
 * "B", the registers PORTB, PINB and DDRB will be used.
 */
#ifndef USB_CFG_INTPORT_BIT
  #if (defined(__AVR_ATmega640__) || defined (__AVR_ATmega128__) || defined(__AVR_ATmega1280__) || defined(__AVR_ATmega1281__) || defined(__AVR_ATmega2560__) || defined(__AVR_ATmega2561__))
    #define USB_CFG_INTPORT_BIT 0
  #else
    #define USB_CFG_INTPORT_BIT 2
  #endif
#endif
/* Not all devices have their INT0 on PD2.
 * Since "INT0" and "USB_CFG_DPLUS_BIT" should get the same signals,
 * map them to be ideally the same:
 * So abstract "USB_CFG_DPLUS_BIT" to this one here.
 */

#ifndef USB_CFG_DMINUS_BIT
  /* This is Revision 3 and later (where PD6 and PD7 were swapped */
  #define USB_CFG_DMINUS_BIT      3    /* Rev.2 and previous was 6 */
#endif
/* This is the bit number in USB_CFG_IOPORT where the USB D- line is connected.
 * This may be any bit in the port.
 */
#ifndef USB_CFG_DPLUS_BIT
  #define USB_CFG_DPLUS_BIT       USB_CFG_INTPORT_BIT
#endif
/* This is the bit number in USB_CFG_IOPORT where the USB D+ line is connected.
 * This may be any bit in the port. Please note that D+ must also be connected
 * to interrupt pin INT0!
 */
#ifndef JUMPER_PORT
  #define JUMPER_PORT		USB_CFG_IOPORTNAME
#endif
/* 
 * jumper is connected to this port
 */
#ifndef JUMPER_BIT
  /* This is Revision 3 and later (where PD6 and PD7 were swapped */
  #define JUMPER_BIT           4       /* Rev.2 and previous was 7 */
#endif
/* 
 * jumper is connected to this bit in port "JUMPER_PORT", active low
 */

#define USB_CFG_CLOCK_KHZ       (F_CPU/1000)
/* Clock rate of the AVR in MHz. Legal values are 12000, 16000 or 16500.
 * The 16.5 MHz version of the code requires no crystal, it tolerates +/- 1%
 * deviation from the nominal frequency. All other rates require a precision
 * of 2000 ppm and thus a crystal!
 * Default if not specified: 12 MHz
 */

/* ----------------------- Optional Hardware Config ------------------------ */

/* #define USB_CFG_PULLUP_IOPORTNAME   D */
/* If you connect the 1.5k pullup resistor from D- to a port pin instead of
 * V+, you can connect and disconnect the device from firmware by calling
 * the macros usbDeviceConnect() and usbDeviceDisconnect() (see usbdrv.h).
 * This constant defines the port on which the pullup resistor is connected.
 */
/* #define USB_CFG_PULLUP_BIT          4 */
/* This constant defines the bit number in USB_CFG_PULLUP_IOPORT (defined
 * above) where the 1.5k pullup resistor is connected. See description
 * above for details.
 */

/* ------------------------------------------------------------------------- */
/* ---------------------- feature / code size options ---------------------- */
/* ------------------------------------------------------------------------- */
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

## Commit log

2021-01-04 add PCB
    [pcb-B_Cu.gbr, pcb-B_Mask.gbr, pcb-B_Paste.gbr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]
2021-01-04 add readme and fabrication files
    [pcb.csv, pcb.kicad_pcb, pcb.sch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]
2021-01-04 add PCB to STEP
    [pad.step, pcb.kicad_pcb]
2021-01-04 update pcb images
2021-01-17 updated PCB to support per-key LEDs
    [twelvekey-B_Cu.gbr, twelvekey-B_Mask.gbr, twelvekey-B_Paste.gbr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]
2021-01-17 added a logo
    [twelvekey.step]
2021-02-17 fix backlight
    [twelvekey-B_Cu.gbr, twelvekey-B_Mask.gbr, twelvekey-B_Paste.gbr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]
2021-03-18 update images
    [twelvekey.kicad_pcb]
2021-04-05 update and added 3d print files
    [bottom.stl, top.stl, twelvekey.kicad_pcb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]
2021-09-30 new version update
    [bottom.step, bottom.stl, top.step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]
2021-10-02 add gerbers
    [twelvekey-B_Cu.gbr, twelvekey-B_Mask.gbr, twelvekey-B_Paste.gbr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]
2024-02-25 update PCB files for KiCAD 8.0
    [bom.csv, positions.csv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]

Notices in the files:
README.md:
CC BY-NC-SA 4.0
